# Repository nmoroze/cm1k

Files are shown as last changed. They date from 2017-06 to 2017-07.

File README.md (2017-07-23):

# CM1K Breakout Board
This repo contains the code and design files for the CM1K breakout board discussed in this [blog post](https://medium.com/@noahmoroze/experiments-with-the-cm1k-neural-net-chip-32b2d5ca723b).

## Hardware
Under the `src/` directory I've included the original Altium files for the schematic and PCB, as well the library files for the crystal oscillator and CM1K. I know Altium is fairly inaccessible, but I've had some trouble getting a good export that works in a free PCB editor. Please contact me if you would like to work with these files, and I'll help you make them accessible to your editor of choice!

The `dist/` directory contains a PDF of the schematic as well as a zip file containing Gerber files for the PCB. This zip file is the exact same as the one I uploaded to Advanced Circuits to purchase this board. 

### BOM
I originally purchased all components from Digikey, and generated the BOM below from that cart. However, the CM1K no longer appears to be available from Digikey. 

| Part | Quantity | Digkey Part Number | Manufacturer Part Number |
|---|---|---|---|
| IC REG LDO 1.2V 0.8A SOT223 | 1 | 497-4240-1-ND | LD1117S12TR |
| IC REG LDO 3.3V 0.8A DPAK | 1 | 497-1236-1-ND | LD1117DT33TR |
| IC ASIC CHIP CM1K 1024 NEURONS | 1 | N/A | N/A |
| OSC XO 27.000MHZ HCMOS TTL SMD | 1 | 535-9263-1-ND | ASFL1-27.000MHZ-EK-T |
| RES SMD 270 OHM 5% 1/10W 0603 | 26 | 311-270GRCT-ND | RC0603JR-07270RL |
| CAP CER 0.1UF 50V Y5V 0603 | 18 | 311-1343-1-ND | CC0603ZRY5V9BB104 |
| RES SMD 120 OHM 5% 1/10W 0603 | 2 | 311-120GRCT-ND | RC0603JR-07120RL |
| CAP CER 10UF 16V X5R 0603 | 2 | 490-7201-1-ND | GRM188R61C106MA73D |
| CAP CER 0.01UF 50V X7R 0603 | 1 | 311-1085-1-ND | CC0603KRX7R9BB103 |
| LED ORANGE CLEAR 0603 SMD | 1 | 160-1445-1-ND | LTST-C191KFKT |

## Code
The code for this board consists of a small collection of fairly short Python scripts. It's not particularly clean or well documented right now, but most of it is short enough that it should be fairly straightforward. I'm not planning to go back and clean it up unless I decide to pursue a larger project using the CM1K. 

The `code/` directory includes:
- `cm1k.py`, a simple library for accessing the CM1K's hardware from Python 
- `test.py`, a small unit test file containing a simple test script 
- `mnist_test.py`, the script I used to run my MNIST KNN experiment documented in the blog post
- `requirements.txt`, the pip requirements for running `mnist_test`

## Licensing
The hardware design files are licensed under [CC BY-NC-SA](https://creativecommons.org/licenses/by-nc-sa/4.0/), and the code is provided under the [MIT license](https://opensource.org/licenses/MIT). Original copyright Noah Moroze, 2017.

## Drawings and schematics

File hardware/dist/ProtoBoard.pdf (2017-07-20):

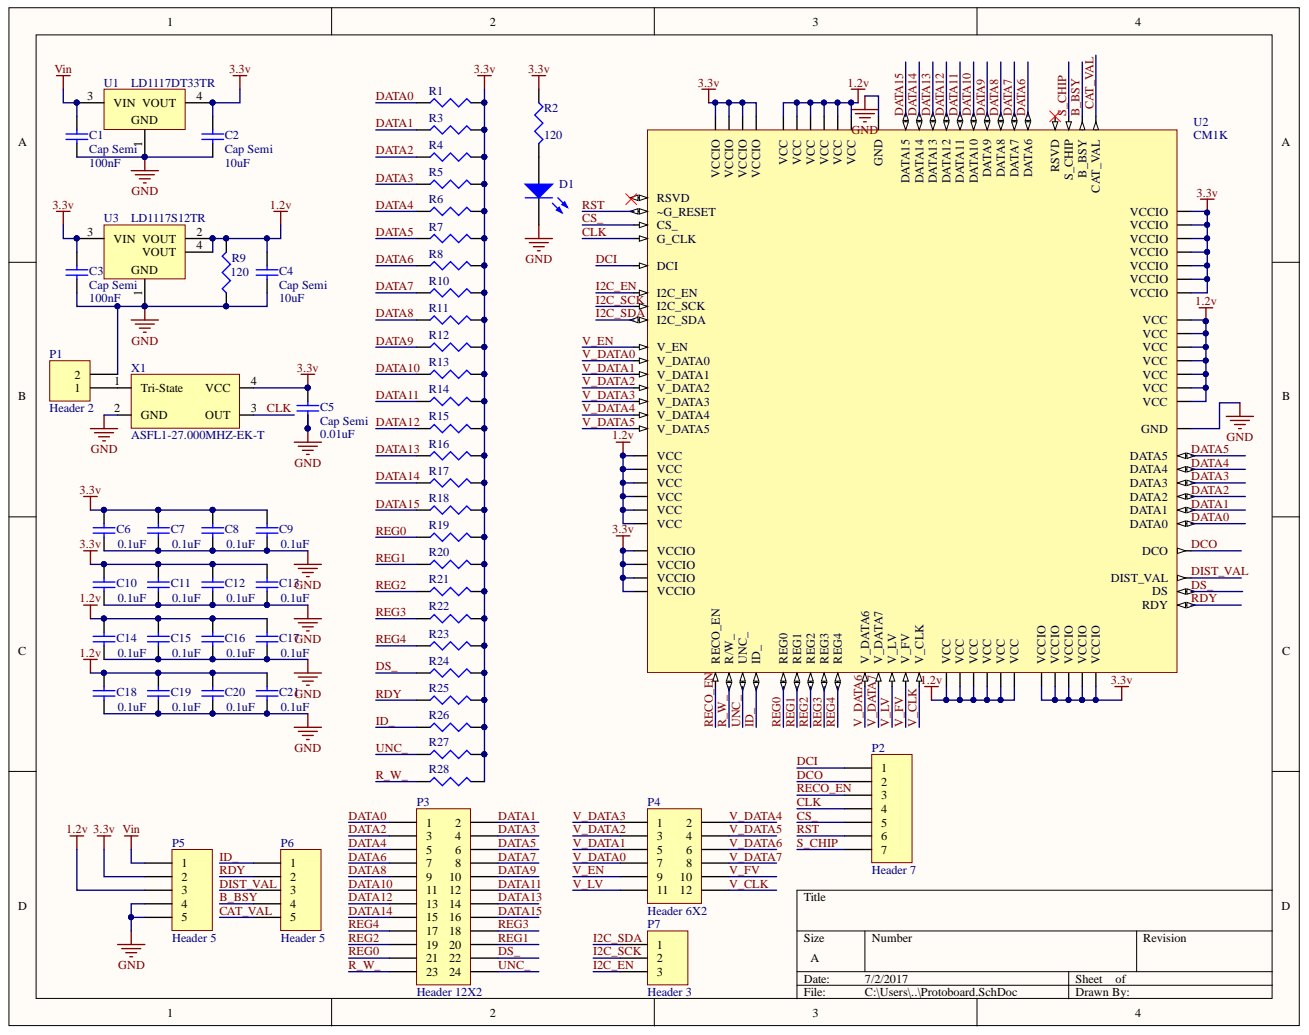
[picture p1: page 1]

VCCIO VCC VCC DCO DATA0 VCCIO DATA1 VCC DATA2 VCCIO DATA3 VCC VCCIO VCC DATA4 VCCIO DATA5

VCCIO VCC VCC GND
VCCIO

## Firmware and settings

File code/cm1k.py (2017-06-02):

import smbus

I2C_ADDRESS = 0x4A

# registers
REG_NSR = 0x0D
REG_GCR = 0x0B
REG_MINIF = 0x06
REG_MAXIF = 0x07
REG_NCR = 0x00
REG_COMP = 0x01
REG_LCOMP = 0x02
REG_INDEXCOMP = 0x03
REG_DIST = 0x03
REG_CAT = 0x04
REG_AIF = 0x05
REG_NID = 0x0A
REG_POWERSAVE = 0x0E
REG_FORGET = 0x0F
REG_NCOUNT = 0x0F
REG_RESETCHAIN = 0x0C

# test registers
REG_TESTCOMP = 0x08
REG_TESTCAT = 0x09

class CM1K(object):
    def __init__(self, bus=1):
        self.bus = smbus.SMBus(bus)

    def read(self, reg):
        word = self.bus.read_word_data(I2C_ADDRESS, reg)
        return ((word>>8)&0xff) + ((word&0xff)<<8) 

    def write(self, reg, value=0):
        self.bus.write_word_data(I2C_ADDRESS, reg, ((value>>8)&0xff)+((value&0xff)<<8))

    def read_component(self):
        data = []
        for _ in xrange(256):
            data.append(self.read(REG_COMP))
        self.write(REG_INDEXCOMP, 0)
        return data

    def broadcast_vector(self, vector):
        for byte in vector[:-1]: 
            self.write(REG_COMP, byte)  
        
        self.write(REG_LCOMP, vector[-1])

    def train_vector(self, vector, category):
        self.broadcast_vector(vector)
        self.write(REG_CAT, category)
        

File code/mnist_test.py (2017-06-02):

from mnist import MNIST
from PIL import Image 
import numpy as np
import random
from cm1k import * 
from tqdm import tqdm
import os
import errno

mndata = MNIST('./mnist')
random.random()
cm1k = CM1K()

def process_image(img):
    img = np.array(img).reshape(28, 28)    
    img = Image.fromarray(img.astype('uint8')).convert('L')
    img = img.resize((16, 16)) # must resize imgs to 16x16 to fit in vector

    resized_img = np.asarray(img).flatten()
    return resized_img

def train_knn():
    print "Loading MNIST training data..."
    data = mndata.load_training()
    print "Finished loading data!"
    data = zip(*data)

    sample = 1024
    training_subset = random.sample(data, sample) 
    print "Training..."
    cm1k.write(REG_FORGET)
    cm1k.write(REG_NSR, 0x10) # put cm1k in sr mode
    for img, label in tqdm(training_subset, desc="Training CM1K", unit="samples"):
        resized_img = process_image(img)
        cm1k.train_vector(resized_img, label+1)
    print "Done training!"


def train(sample=1024):
    print "Loading MNIST training data..."
    data = mndata.load_training()
    print "Finished loading data!"
    data = zip(*data)

    training_subset = random.sample(data, sample) 
    print "Training..."
    cm1k.write(REG_NSR, 0x20)
    cm1k.write(REG_FORGET)
    for img, label in tqdm(training_subset, desc="Training CM1K", unit="samples"):
        resized_img = process_image(img)
        cm1k.train_vector(resized_img, label+1)
    print "Done training!"

def output_models(path):
    try:
        os.makedirs(path)
    except OSError as exception:
        if exception.errno != errno.EEXIST:
            raise
                    
    cm1k.write(REG_NSR, 0x10) # put cm1k into NSR mode
    cm1k.write(REG_RESETCHAIN)
    while True:
        data = cm1k.read_component()
        cat = cm1k.read(REG_CAT)
        img = np.array(data).reshape(16, 16)
        img = Image.fromarray(img.astype('uint8')).convert('L')
        img.save('%s/%d.bmp' % (path, (cat-1)))
        print cat
        if cat==0:
            break
    cm1k.write(REG_NSR, 0x00)

def test(sample=100):
    data = mndata.load_testing()
    data = zip(*data)
    data = random.sample(data, sample)
    correct = 0.0
    total = 0.0
    print "Testing!"
    cm1k.write(REG_NSR, 0x20) # put into KNN mode
    t = tqdm(data, desc="Testing CM1K", unit="samples")
    for img, label in t:
        img = process_image(img)
        cm1k.broadcast_vector(img)
        cm1k.read(REG_DIST)
        cat = cm1k.read(REG_CAT)
        total += 1
        if label == cat + 1:
            correct += 1
        t.set_postfix({"%": correct/total*100})
    cm1k.write(REG_NSR, 0x0) # reset from KNN mode
    print "Done testing!!"
    print float(correct)/total

def test_knn(k=3, sample=100):
    print "Loading test data..."
    data = mndata.load_testing()
    data = zip(*data)
    data = random.sample(data, sample)
    print "Done loading test data!"
    correct = 0.0
    total = 0.0
    cm1k.write(REG_NSR, 0x20) # put into KNN mode
    t = tqdm(data, desc="Testing CM1K w/ KNN (k=%d)" % k, unit="samples")
    for img, label in t:
        img = process_image(img)
        cm1k.broadcast_vector(img)
        categories = [0] * 10
        for _ in xrange(k):
            cm1k.read(REG_DIST)
            cat = cm1k.read(REG_CAT)
            categories[cat-1] += 1
        max_val = max(categories)
        identified = categories.index(max_val)

        total += 1
        if label == identified:
            correct += 1
        t.set_postfix({"%": correct/total*100})

    cm1k.write(REG_NSR, 0x0) # reset from KNN mode
    print "Done testing!!"
    print "Correctly identified: %.2f%%" %  (float(correct)/total * 100)

if __name__ == '__main__':
    train(1024)
    test()

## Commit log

2017-05-29 Fixed bugs in refactored cm1k
    [cm1k.py, test.py]
2017-07-20 Add files for breakout board
    [CM1K.PcbLib, CM1K.SchLib, Oscillator.PcbLib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]
2017-07-23 Remove ASCII export files that don't seem to work
    [Protoboard.sch]
